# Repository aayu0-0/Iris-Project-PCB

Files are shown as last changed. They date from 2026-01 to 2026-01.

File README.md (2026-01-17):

# Iris-Project-PCB
This repository contains the design files for a **custom microcontroller-based embedded PCB**, developed with a focus on reliable power delivery, structured system design, and stable real-world operation.

The project follows a **hierarchical schematic approach**, separating power, MCU, and sensor subsystems to improve clarity and maintainability. Design decisions were guided by datasheet-level analysis and practical electrical constraints rather than trial-and-error.

## Project Scope
- Schematic design of power regulation, MCU core, and peripheral interfaces
- PCB layout with attention to grounding, decoupling, and routing discipline
- Component and package selection considering availability and manufacturability
- Mechanical verification using 3D STEP export

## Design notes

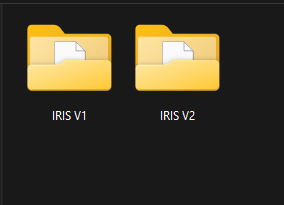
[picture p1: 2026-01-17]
Docs/Project.png

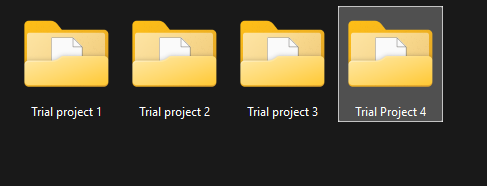
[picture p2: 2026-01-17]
Docs/Trials.png

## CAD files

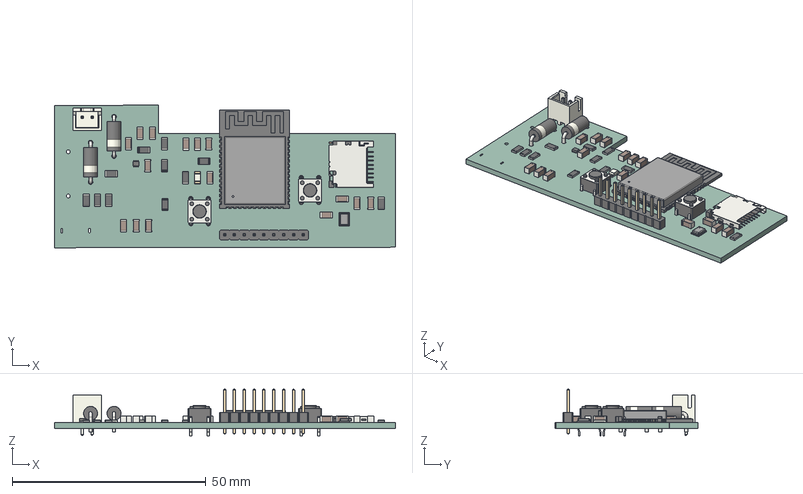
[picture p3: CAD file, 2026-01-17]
IRIS V2/IRIS V2.step
87.9 x 36.8 x 12.0 mm
R_1206_3216Metric x 11
C_1206_3216Metric x 15
JST_XH_B2B-XH-A_1x02_P2.50mm_Vertical
SW_PUSH_6mm x 2
LED_1206_3216Metric
Knowles_SPH0645LM4H-6_3.5x2.65mm
D_DO-15_P10.16mm_Horizontal x 2
SOT-563
PinHeader_1x09_P2.54mm_Vertical
ESP32-S3-WROOM-1
microSD_HC_Hirose_DM3D-SF
IRIS V2_PCB

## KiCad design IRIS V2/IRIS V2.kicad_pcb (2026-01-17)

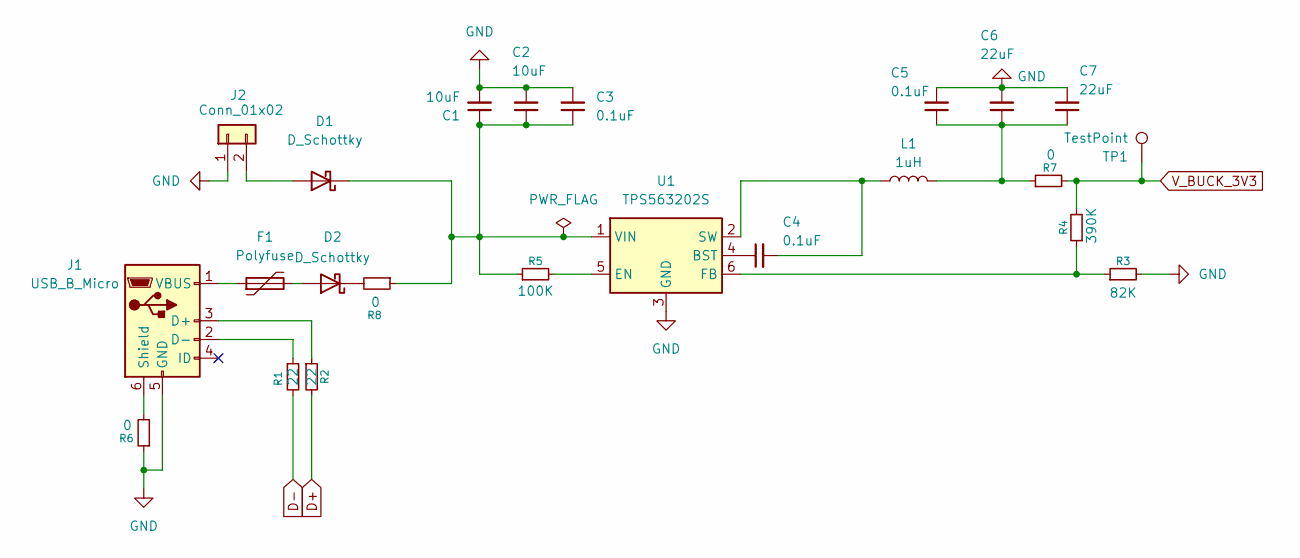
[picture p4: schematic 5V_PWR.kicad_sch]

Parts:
C1, C2: 10uF; C_1206_3216Metric
C3, C4, C5: 0.1uF; C_1206_3216Metric
C6, C7: 22uF; C_1206_3216Metric
D1, D2: D_Schottky; D_DO-15_P10.16mm_Horizontal
F1: Polyfuse; Fuse_Littelfuse-LVR100
J1: USB_B_Micro; USB_Micro-B_GCT_USB3076-30-A
J2: Conn_01x02; JST_XH_B2B-XH-A_1x02_P2.50mm_Vertical
L1: 1uH; L_6.3x6.3_H3
R1, R2: 22; R_1206_3216Metric
R3: 82K; R_1206_3216Metric
R4: 390K; R_1206_3216Metric
R5: 100K; R_1206_3216Metric
R6, R7, R8: 0; R_1206_3216Metric
TP1: TestPoint; TestPoint_Pad_1.0x1.0mm
U1: TPS563202S; SOT-563

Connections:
D+: R2.2; also elsewhere on the board
D-: R1.2; also elsewhere on the board
GND: C1.2, C2.2, C3.2, C5.2, C6.2, C7.2, J1.5 (GND), J2.1, R3.2, R6.1, U1.3 (GND); also elsewhere on the board
unnamed: C5.1, C6.1, C7.1, L1.2, R7.1
unnamed: D1.2 (A), J2.2
unnamed: C1.1, C2.1, C3.1, D1.1 (K), R5.1, R8.1, U1.1 (VIN)
unnamed: D2.2 (A), F1.2
unnamed: D2.1 (K), R8.2
unnamed: J1.3 (D+), R2.1
unnamed: J1.2 (D-), R1.1
unnamed: J1.6 (Shield), R6.2
unnamed: F1.1, J1.1 (VBUS)
unnamed: C4.1, U1.4 (BST)
unnamed: R5.2, U1.5 (EN)
unnamed: R3.1, R4.1, U1.6 (FB)
unnamed: C4.2, L1.1, U1.2 (SW)
V_BUCK_3V3: R4.2, R7.2, TP1.1; also elsewhere on the board

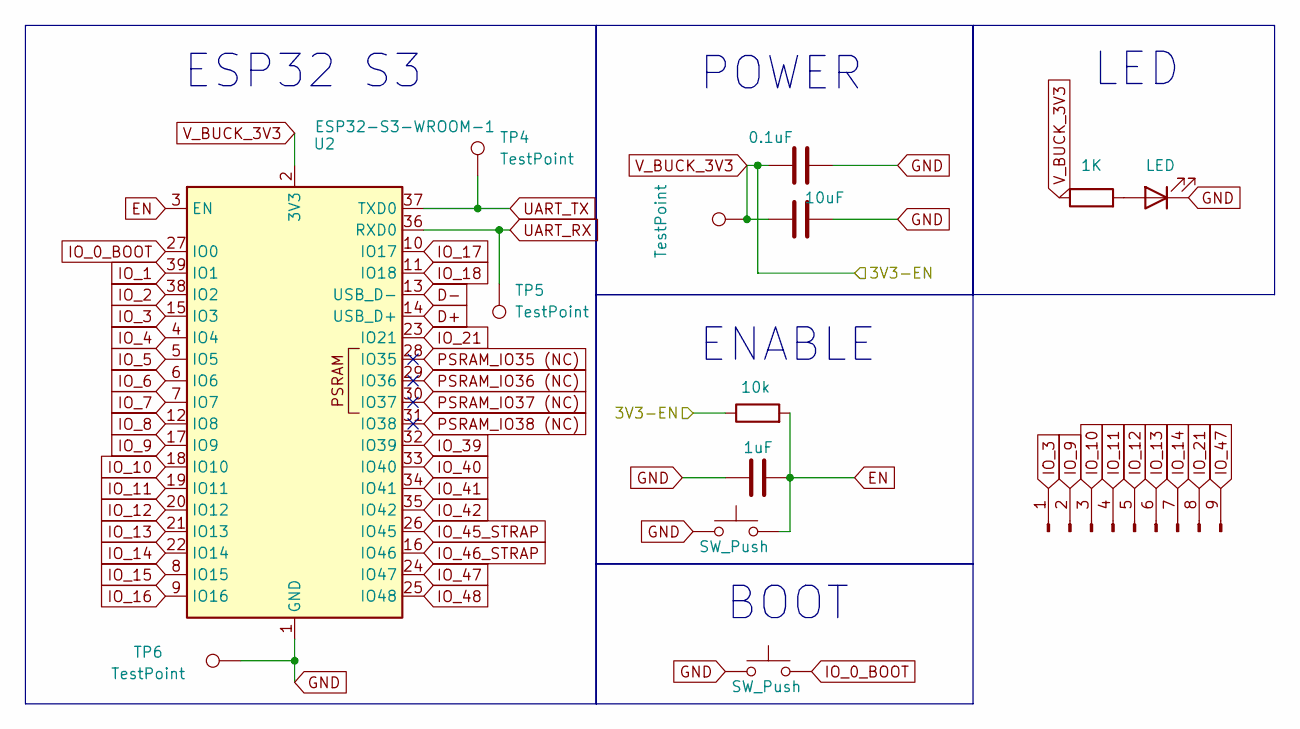
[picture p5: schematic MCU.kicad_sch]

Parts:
C9: 10uF; C_1206_3216Metric
C10: 1uF; C_1206_3216Metric
C11: 0.1uF; C_1206_3216Metric
D3: LED; LED_1206_3216Metric_Pad1.42x1.75mm_HandSolder
J4: Conn_01x09_Pin; PinHeader_1x09_P2.54mm_Vertical
R10: 10k; R_1206_3216Metric
R11: 1K; R_1206_3216Metric
SW1, SW2: SW_Push; SW_PUSH_6mm
TP4, TP5, TP6, TP7: TestPoint; TestPoint_Pad_1.0x1.0mm
U2: ESP32-S3-WROOM-1

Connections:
CS: U2.39 (IO1); also elsewhere on the board
D+: U2.14 (USB_D+); also elsewhere on the board
D-: U2.13 (USB_D-); also elsewhere on the board
EN: C10.1, R10.2, SW1.2, U2.3 (EN)
GND: C9.2, C10.2, C11.2, D3.1 (K), SW1.1, SW2.1, TP6.1, U2.1 (GND), U2.40 (GND), U2.41 (GND); also elsewhere on the board
IO_0_BOOT: SW2.2, U2.27 (IO0)
IO_2: U2.38 (IO2); also elsewhere on the board
IO_3: J4.1, U2.15 (IO3)
IO_4: U2.4 (IO4)
IO_5: U2.5 (IO5)
IO_6: U2.6 (IO6)
IO_7: U2.7 (IO7)
IO_8: U2.12 (IO8)
IO_9: J4.2, U2.17 (IO9)
IO_10: J4.3, U2.18 (IO10)
IO_11: J4.4, U2.19 (IO11)
IO_12: J4.5, U2.20 (IO12)
IO_13: J4.6, U2.21 (IO13)
IO_14: J4.7, U2.22 (IO14)
IO_15: U2.8 (IO15)
IO_16: U2.9 (IO16)
IO_17: U2.10 (IO17)
IO_18: U2.11 (IO18)
IO_21: J4.8, U2.23 (IO21)
IO_39: U2.32 (IO39); also elsewhere on the board
IO_40: U2.33 (IO40); also elsewhere on the board
IO_41: U2.34 (IO41); also elsewhere on the board
IO_42: U2.35 (IO42); also elsewhere on the board
IO_45_STRAP: U2.26 (IO45)
IO_46_STRAP: U2.16 (IO46)
IO_47: J4.9, U2.24 (IO47)
IO_48: U2.25 (IO48); also elsewhere on the board
unnamed: D3.2 (A), R11.2
PSRAM_IO35 (NC): U2.28 (IO35)
PSRAM_IO36 (NC): U2.29 (IO36)
PSRAM_IO37 (NC): U2.30 (IO37)
PSRAM_IO38 (NC): U2.31 (IO38)
UART_RX: TP5.1, U2.36 (RXD0)
UART_TX: TP4.1, U2.37 (TXD0)
V_BUCK_3V3: C9.1, C11.1, R10.1, R11.1, TP7.1, U2.2 (3V3); also elsewhere on the board

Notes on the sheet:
ESP32 S3
POWER
ENABLE
BOOT
LED

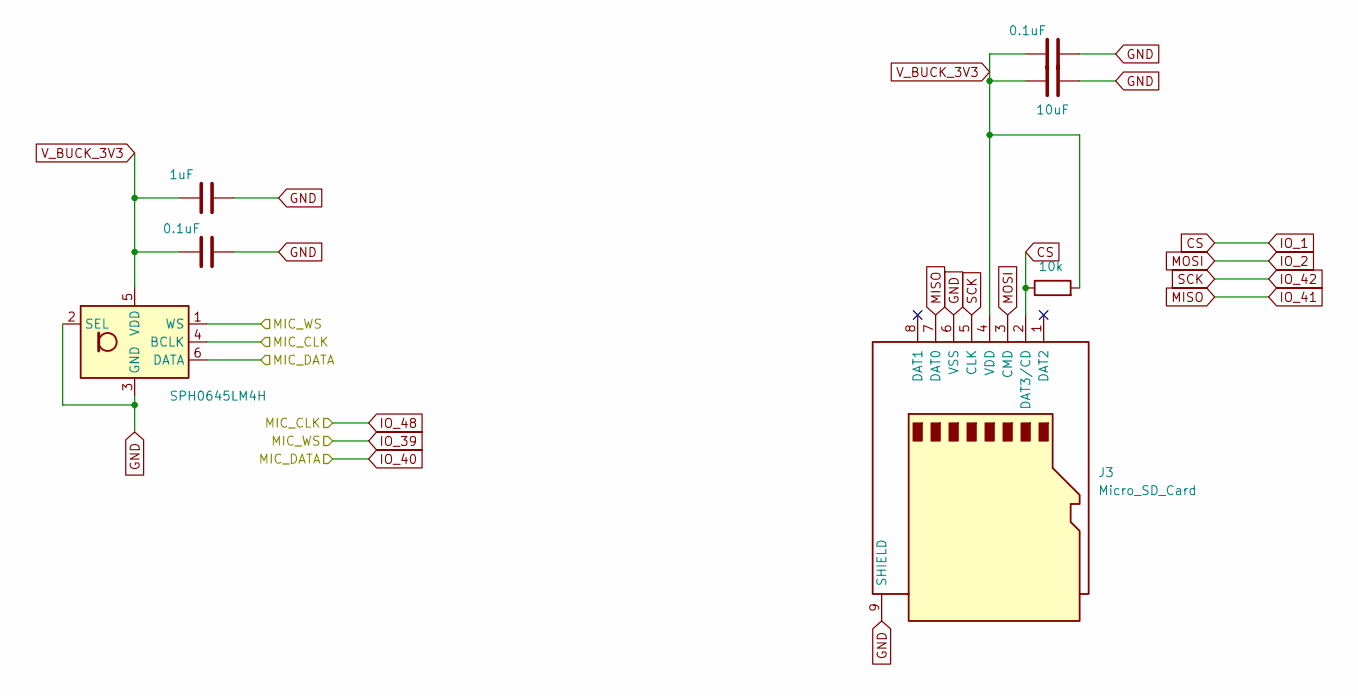
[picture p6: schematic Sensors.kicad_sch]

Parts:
C8, C13: 0.1uF; C_1206_3216Metric
C12: 1uF; C_1206_3216Metric
C14: 10uF; C_1206_3216Metric
J3: Micro_SD_Card; microSD_HC_Hirose_DM3D-SF
MK1: SPH0645LM4H; Knowles_SPH0645LM4H-6_3.5x2.65mm
R13: 10k; R_1206_3216Metric

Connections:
CS: J3.2 (DAT3/CD), R13.1; also elsewhere on the board
GND: C8.2, C12.2, C13.2, C14.2, J3.6 (VSS), J3.9 (SHIELD), MK1.2 (SEL), MK1.3 (GND); also elsewhere on the board
IO_2: J3.3 (CMD); also elsewhere on the board
IO_39: MK1.1 (WS); also elsewhere on the board
IO_40: MK1.6 (DATA); also elsewhere on the board
IO_41: J3.7 (DAT0); also elsewhere on the board
IO_42: J3.5 (CLK); also elsewhere on the board
IO_48: MK1.4 (BCLK); also elsewhere on the board
V_BUCK_3V3: C8.1, C12.1, C13.1, C14.1, J3.4 (VDD), MK1.5 (VDD), R13.2; also elsewhere on the board

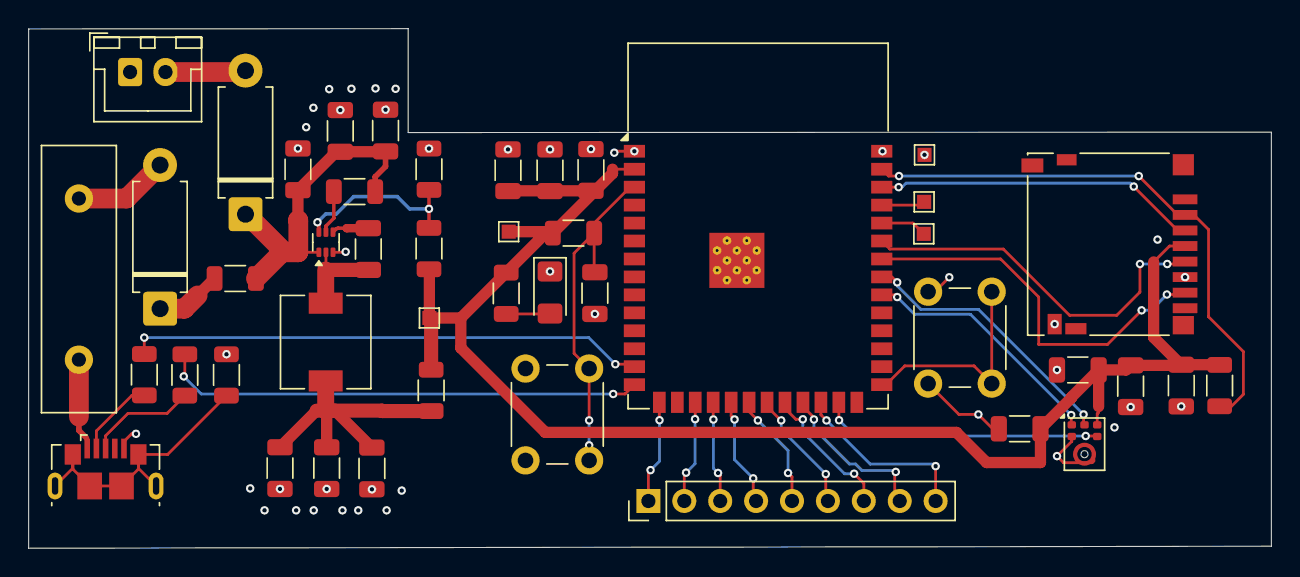
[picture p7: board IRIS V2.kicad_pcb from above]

Board: 2 copper layers, 87.9 x 36.8 mm, 45 parts (0 on the bottom side), 38 nets.

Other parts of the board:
C8#2: 0.1uF; C_1206_3216Metric

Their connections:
GND: C8#2.2; also elsewhere on the board
V_BUCK_3V3: C8#2.1; also elsewhere on the board
